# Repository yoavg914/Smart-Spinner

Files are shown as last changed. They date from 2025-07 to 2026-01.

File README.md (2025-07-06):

# Smart-Spinner
# Project A - ECE Technion - Smart Spinner

This project is a custom-built smart spinning top system designed to sense, analyze, and display rotational data in real time.
The system integrates a microcontroller, motion sensors, battery management, and wireless communication.

## Features
- Motion sensing using LSM6DSV (accelerometer + gyroscope)
- ESP32-S3 for wireless communication and data processing
- Rechargeable power system using 18650 batteries and a buck converter
- Optional remote-controlled mechanical extension via reserved hammer layout

## Goals
- Analyze spin speed and stability
- Visualize real-time motion data
- Build a modular, embedded system with future expansion in mind

## Status
🚧 Work in progress — hardware assembly and firmware development underway.

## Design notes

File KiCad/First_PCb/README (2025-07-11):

here will be all the files of the lower PCB - The main PCB.

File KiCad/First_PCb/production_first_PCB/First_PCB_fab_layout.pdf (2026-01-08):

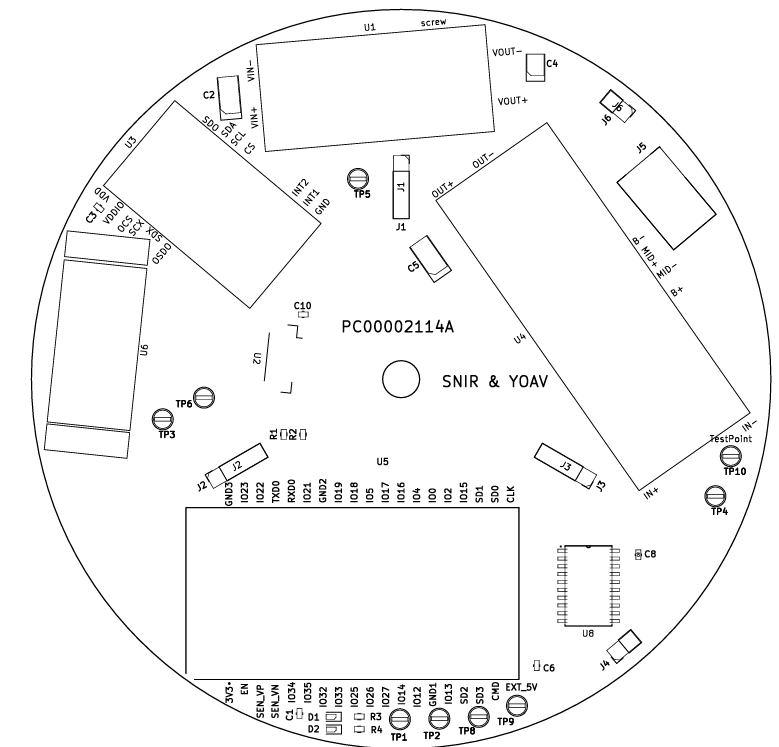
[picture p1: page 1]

First PCB – front layout

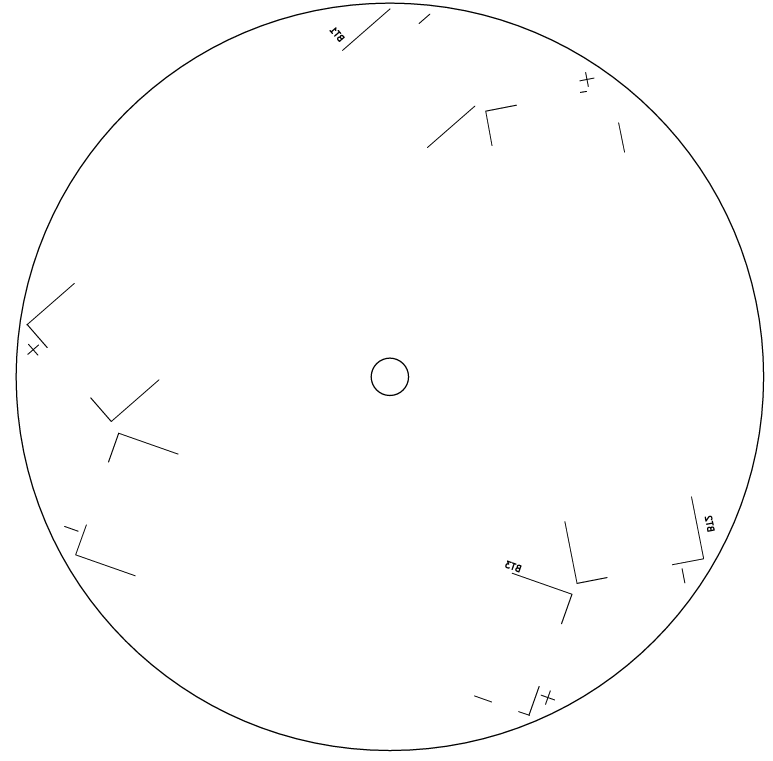
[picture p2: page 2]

First PCB – Back Layout

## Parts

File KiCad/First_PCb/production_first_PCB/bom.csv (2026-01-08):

Designator | Footprint | Quantity | Value | LCSC Part #
BT1, BT2, BT3 | battery_holder | 3 | Battery Holder
C1, C10, C3, C6, C8 | 0603 | 5 | 10u
C2, C5 | CP_EIA-6032-28_Kemet-C_HandSolder | 2 | 47u
C4 | CP_EIA-3528-12_Kemet-T_HandSolder | 1 | 47u
D1 | 0603 | 1 | red_LED
D2 | 0603 | 1 | green_LED
J1, J2, J3 | PinSocket_1x04_P2.54mm_Vertical | 3 | Conn_01x04_Socket
J4, J6 | PinHeader_1x02_P2.54mm_Vertical | 2 | Conn_01x02_Pin
J5 | NINIGI_DC-005 | 1 | DC-005
R1, R2 | 0603 | 2 | 10
R3, R4 | 0603 | 2 | 250
TP1, TP10, TP2, TP3, TP4, TP5, TP6, TP8, TP9 | TestPoint_Loop_D2.60mm_Drill1.4mm_Beaded | 9 | TestPoint
U1 | MT3608_no_conn_TH | 1 | MT3608 - No Connector
U2 | JST_GH125 | 1 | GH1.25
U3 | STEVAL-MKI239A | 1 | STEVAL-MKI239A
U4 | PWR_SPLY12V_TH | 1 | EGBO UPS
U5 | MODULE_ESP32-DEVKITC-32D-TH | 1 | ESP32-DEVKITC-32D
U6 | TF_LUNA_mechanics | 1 | TF_LUNA_mechanics
U8 | 74HCT244D-SOIC20 | 1 | 74HCT244D

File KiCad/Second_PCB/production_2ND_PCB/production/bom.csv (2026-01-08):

Designator | Footprint | Quantity | Value | LCSC Part #
C1, C2, C3, C4 | CP_EIA-3528-12_Kemet-T_HandSolder | 4 | 47u
D1, D10, D11, D12, D13, D14, D15, D16, D17, D18, D19, D2, D20, D21, D22, D23, D24, D25, D26, D27, D28, D29, D3, D30, D31, D32, D33, D34, D35, D36, D37, D38, D39, D4, D40, D5, D6, D7, D8, D9 | LED-APA102-2020_EDITED | 40 | APA102-2020
J1, J2, J3 | PinSocket_1x04_P2.54mm_Vertical | 3 | Conn_01x04_Pin
TP1, TP2, TP3, TP4, TP5 | TestPoint_Loop_D2.60mm_Drill1.4mm_Beaded | 5 | TestPoint

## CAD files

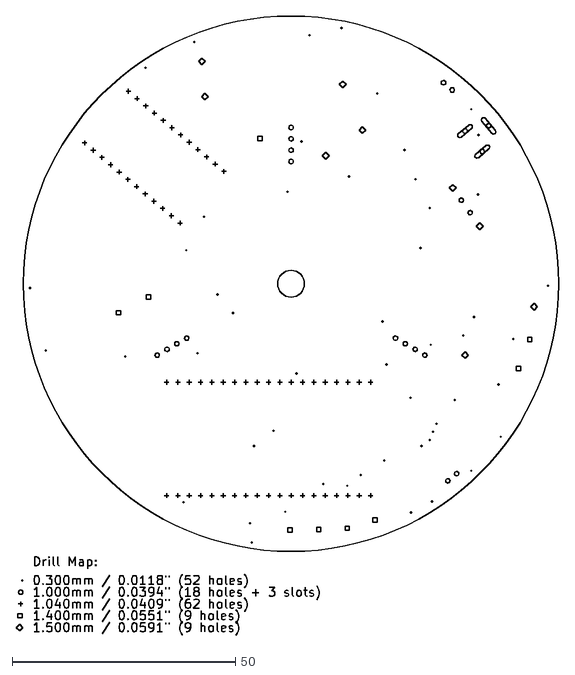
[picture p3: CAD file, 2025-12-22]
KiCad/First_PCb/first_PCB-PTH-drl_map.dxf
121.6 x 138.7

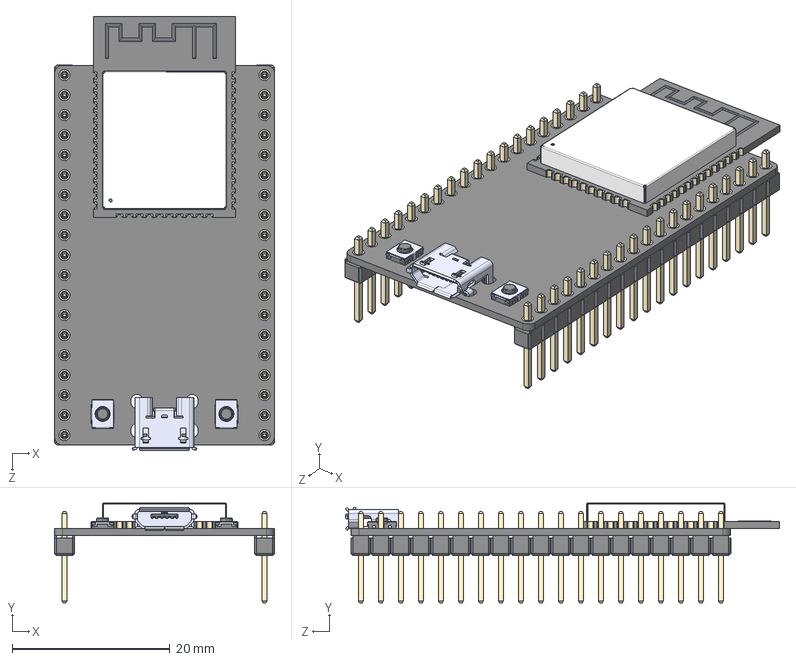
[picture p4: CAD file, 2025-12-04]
KiCad/First_PCb/scematic_symbols/ESP32-DEVKITC-32D/ESP32-DEVKITC-32D.step
27.9 x 12.7 x 55.1 mm
board
header x 2
ESP32-WROOM-32D
micro usb
button x 2

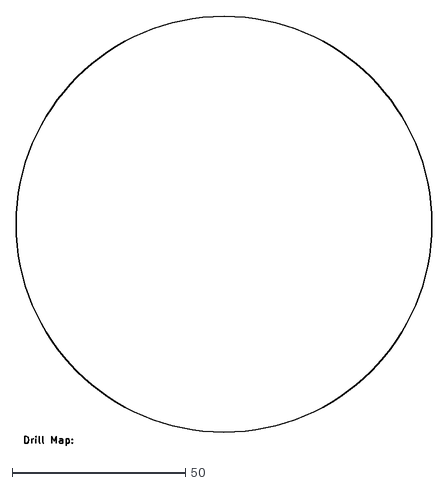
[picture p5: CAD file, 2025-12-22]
KiCad/Second_PCB/2ND_PCB-NPTH-drl_map.dxf
120.0 x 123.9

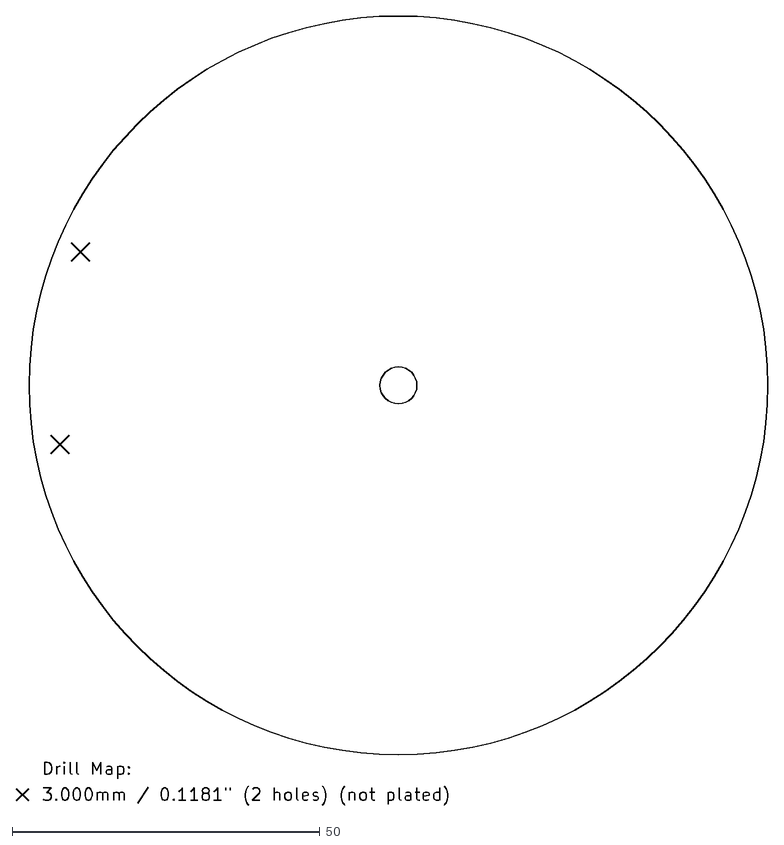
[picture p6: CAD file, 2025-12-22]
KiCad/First_PCb/first_PCB-NPTH-drl_map.dxf
122.1 x 128.2

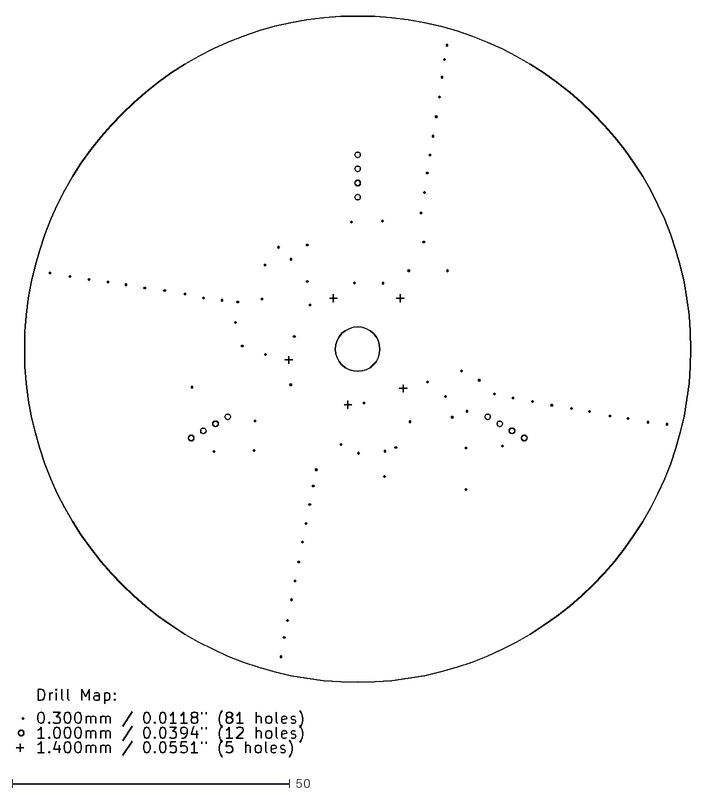
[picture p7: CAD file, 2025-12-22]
KiCad/Second_PCB/2ND_PCB-PTH-drl_map.dxf
121.5 x 133.5

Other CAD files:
3D_Files/spinning-top.f3z

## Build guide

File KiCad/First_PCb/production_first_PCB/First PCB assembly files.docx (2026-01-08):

PC00002114A – Snir & Yoav


First PCB – front layout

PC00002114A – Snir & Yoav

First PCB – Back Layout


Designator | Footprint | Quantity | Value
BT1, BT2, BT3 | battery_holder | 3 | Battery Holder
C1, C10, C3, C6, C8 | 603 | 5 | 10u
C2, C5 | CP_EIA-6032-28_Kemet-C_HandSolder | 2 | 47u
C4 | CP_EIA-3528-12_Kemet-T_HandSolder | 1 | 47u
D1 | 603 | 1 | red_LED
D2 | 603 | 1 | green_LED
J1, J2, J3 | PinSocket_1x04_P2.54mm_Vertical | 3 | Conn_01x04_Socket
J4, J6 | PinHeader_1x02_P2.54mm_Vertical | 2 | Conn_01x02_Pin
J5 | NINIGI_DC-005 | 1 | DC-005
R1, R2 | 603 | 2 | 10
R3, R4 | 603 | 2 | 250
TP1, TP10, TP2, TP3, TP4, TP5, TP6, TP8, TP9 | TestPoint_Loop_D2.60mm_Drill1.4mm_Beaded | 9 | TestPoint
U1 | MT3608_no_conn_TH | 1 | MT3608 - No Connector
U2 | JST_GH125 | 1 | GH1.25
U3 | STEVAL-MKI239A | 1 | STEVAL-MKI239A
U4 | PWR_SPLY12V_TH | 1 | EGBO UPS
U5 | MODULE_ESP32-DEVKITC-32D-TH | 1 | ESP32-DEVKITC-32D
U6 | TF_LUNA_mechanics | 1 | TF_LUNA_mechanics
U8 | 74HCT244D-SOIC20 | 1 | 74HCT244D

PC00002114A – Snir & Yoav

First PCB – BOM

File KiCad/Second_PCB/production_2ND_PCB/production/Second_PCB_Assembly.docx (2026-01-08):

PC00002115A – SNIR & YOAV - 2ND PCB BOTTOM SIDE

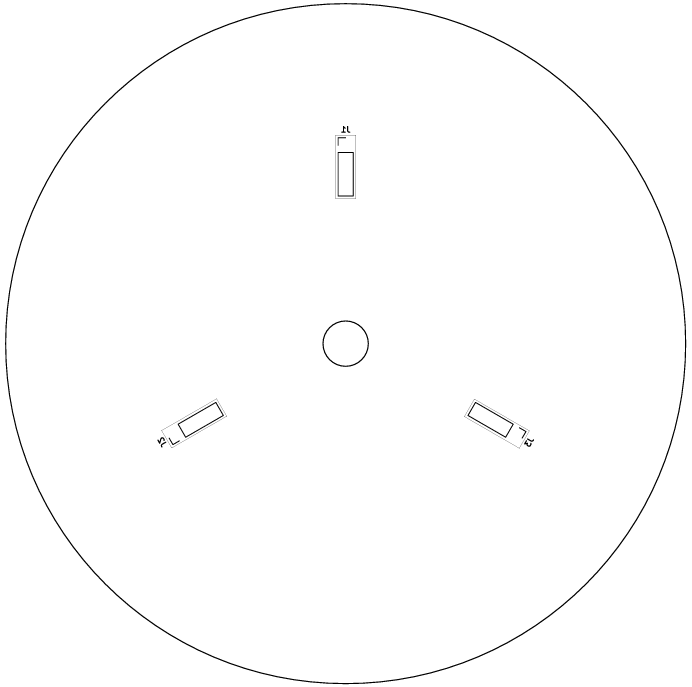
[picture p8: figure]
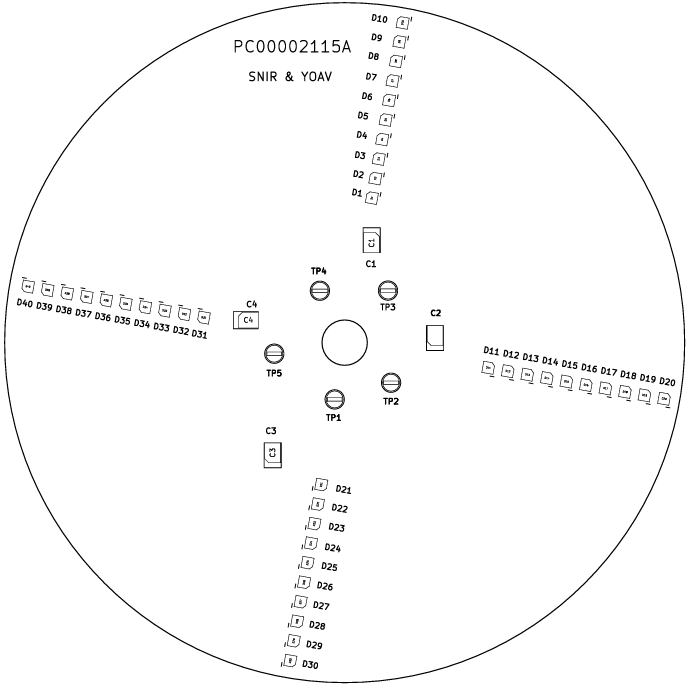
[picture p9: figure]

PC00002115A – SNIR & YOAV - 2ND PCB TOP SIDE

BOM

Designator | Footprint | Quantity | Value
C1, C2, C3, C4 | CP_EIA-3528-12_Kemet-T_HandSolder | 4 | 47u
D1, D10, D11, D12, D13, D14, D15, D16, D17, D18, D19, D2, D20, D21, D22, D23, D24, D25, D26, D27, D28, D29, D3, D30, D31, D32, D33, D34, D35, D36, D37, D38, D39, D4, D40, D5, D6, D7, D8, D9 | LED-APA102-2020_EDITED | 40 | APA102-2020
J1, J2, J3 | PinSocket_1x04_P2.54mm_Vertical | 3 | Conn_01x04_Pin
TP1, TP2, TP3, TP4, TP5 | TestPoint_Loop_D2.60mm_Drill1.4mm_Beaded | 5 | TestPoint

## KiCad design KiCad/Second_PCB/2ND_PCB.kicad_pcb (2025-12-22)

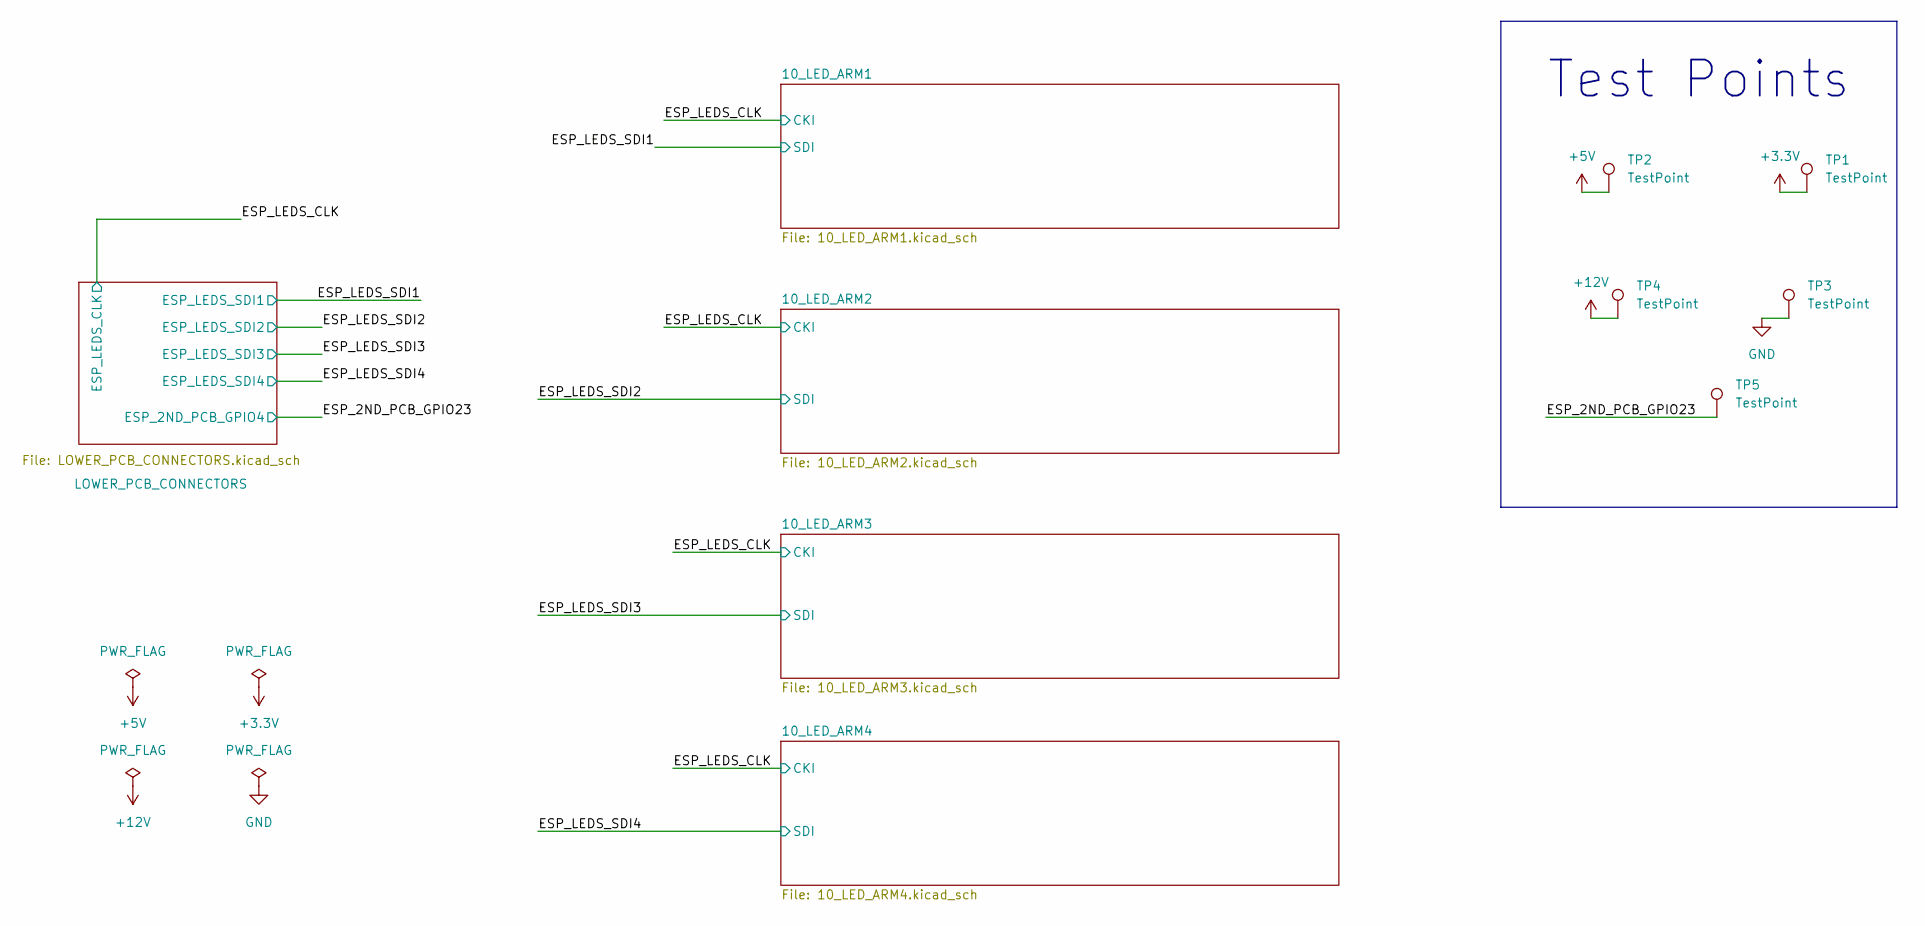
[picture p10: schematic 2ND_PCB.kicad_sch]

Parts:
TP1, TP2, TP3, TP4, TP5: TestPoint; TestPoint_Loop_D2.60mm_Drill1.4mm_Beaded

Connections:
+3.3V: TP1.1; also elsewhere on the board
+5V: TP2.1; also elsewhere on the board
+12V: TP4.1; also elsewhere on the board
/ESP_2ND_PCB_GPIO23: TP5.1; also elsewhere on the board
GND: TP3.1; also elsewhere on the board

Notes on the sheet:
Test Points

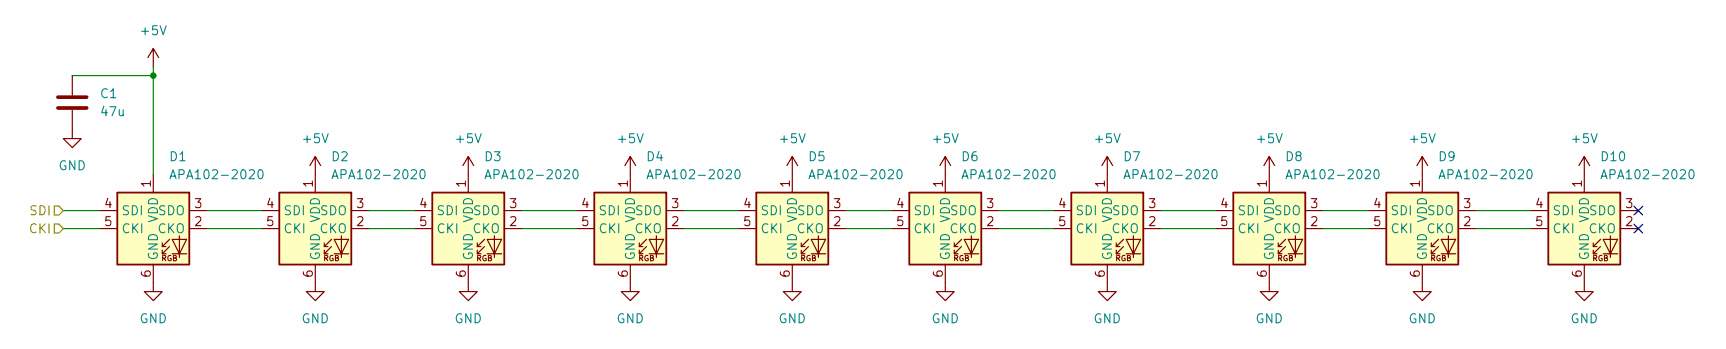
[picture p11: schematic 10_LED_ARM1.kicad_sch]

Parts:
C1: 47u; CP_EIA-3528-12_Kemet-T_HandSolder
D1, D2, D3, D4, D5, D6, D7, D8, D9, D10: APA102-2020; LED-APA102-2020_EDITED

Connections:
+5V: C1.1, D1.1 (VDD), D2.1 (VDD), D3.1 (VDD), D4.1 (VDD), D5.1 (VDD), D6.1 (VDD), D7.1 (VDD), D8.1 (VDD), D9.1 (VDD), D10.1 (VDD); also elsewhere on the board
/ESP_LEDS_CLK: D1.5 (CKI); also elsewhere on the board
/ESP_LEDS_SDI1: D1.4 (SDI); also elsewhere on the board
GND: C1.2, D1.6 (GND), D2.6 (GND), D3.6 (GND), D4.6 (GND), D5.6 (GND), D6.6 (GND), D7.6 (GND), D8.6 (GND), D9.6 (GND), D10.6 (GND); also elsewhere on the board
unnamed: D1.2 (CKO), D2.5 (CKI)
unnamed: D1.3 (SDO), D2.4 (SDI)
unnamed: D2.2 (CKO), D3.5 (CKI)
unnamed: D2.3 (SDO), D3.4 (SDI)
unnamed: D3.2 (CKO), D4.5 (CKI)
unnamed: D3.3 (SDO), D4.4 (SDI)
unnamed: D4.2 (CKO), D5.5 (CKI)
unnamed: D4.3 (SDO), D5.4 (SDI)
unnamed: D5.2 (CKO), D6.5 (CKI)
unnamed: D5.3 (SDO), D6.4 (SDI)
unnamed: D6.2 (CKO), D7.5 (CKI)
unnamed: D6.3 (SDO), D7.4 (SDI)
unnamed: D7.2 (CKO), D8.5 (CKI)
unnamed: D7.3 (SDO), D8.4 (SDI)
unnamed: D8.2 (CKO), D9.5 (CKI)
unnamed: D8.3 (SDO), D9.4 (SDI)
unnamed: D9.2 (CKO), D10.5 (CKI)
unnamed: D9.3 (SDO), D10.4 (SDI)

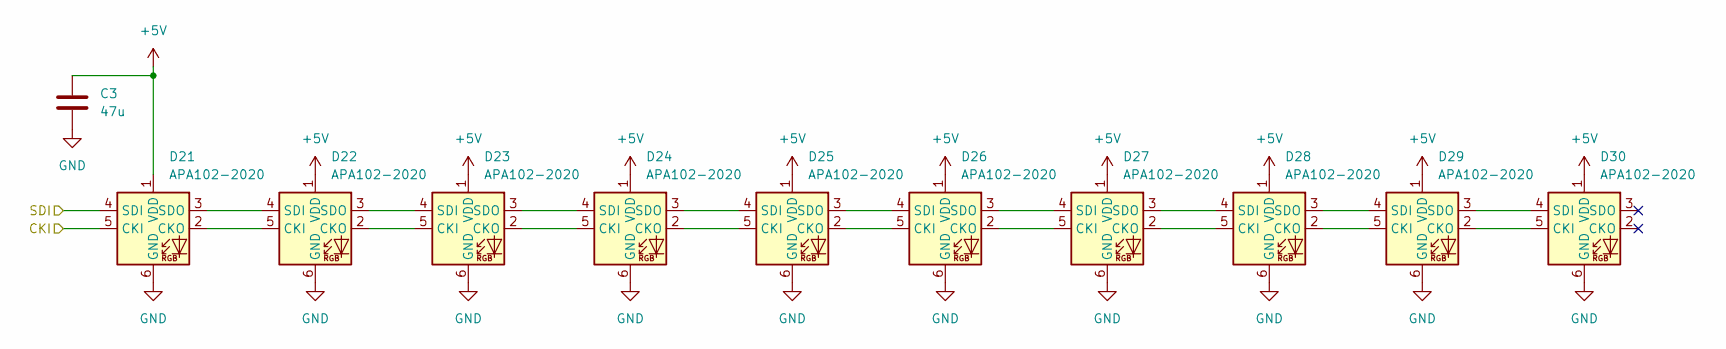
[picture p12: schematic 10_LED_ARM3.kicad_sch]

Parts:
C3: 47u; CP_EIA-3528-12_Kemet-T_HandSolder
D21, D22, D23, D24, D25, D26, D27, D28, D29, D30: APA102-2020; LED-APA102-2020_EDITED

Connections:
+5V: C3.1, D21.1 (VDD), D22.1 (VDD), D23.1 (VDD), D24.1 (VDD), D25.1 (VDD), D26.1 (VDD), D27.1 (VDD), D28.1 (VDD), D29.1 (VDD), D30.1 (VDD); also elsewhere on the board
/ESP_LEDS_CLK: D21.5 (CKI); also elsewhere on the board
/ESP_LEDS_SDI3: D21.4 (SDI); also elsewhere on the board
GND: C3.2, D21.6 (GND), D22.6 (GND), D23.6 (GND), D24.6 (GND), D25.6 (GND), D26.6 (GND), D27.6 (GND), D28.6 (GND), D29.6 (GND), D30.6 (GND); also elsewhere on the board
unnamed: D21.2 (CKO), D22.5 (CKI)
unnamed: D21.3 (SDO), D22.4 (SDI)
unnamed: D22.2 (CKO), D23.5 (CKI)
unnamed: D22.3 (SDO), D23.4 (SDI)
unnamed: D23.2 (CKO), D24.5 (CKI)
unnamed: D23.3 (SDO), D24.4 (SDI)
unnamed: D24.2 (CKO), D25.5 (CKI)
unnamed: D24.3 (SDO), D25.4 (SDI)
unnamed: D25.2 (CKO), D26.5 (CKI)
unnamed: D25.3 (SDO), D26.4 (SDI)
unnamed: D26.2 (CKO), D27.5 (CKI)
unnamed: D26.3 (SDO), D27.4 (SDI)
unnamed: D27.2 (CKO), D28.5 (CKI)
unnamed: D27.3 (SDO), D28.4 (SDI)
unnamed: D28.2 (CKO), D29.5 (CKI)
unnamed: D28.3 (SDO), D29.4 (SDI)
unnamed: D29.2 (CKO), D30.5 (CKI)
unnamed: D29.3 (SDO), D30.4 (SDI)

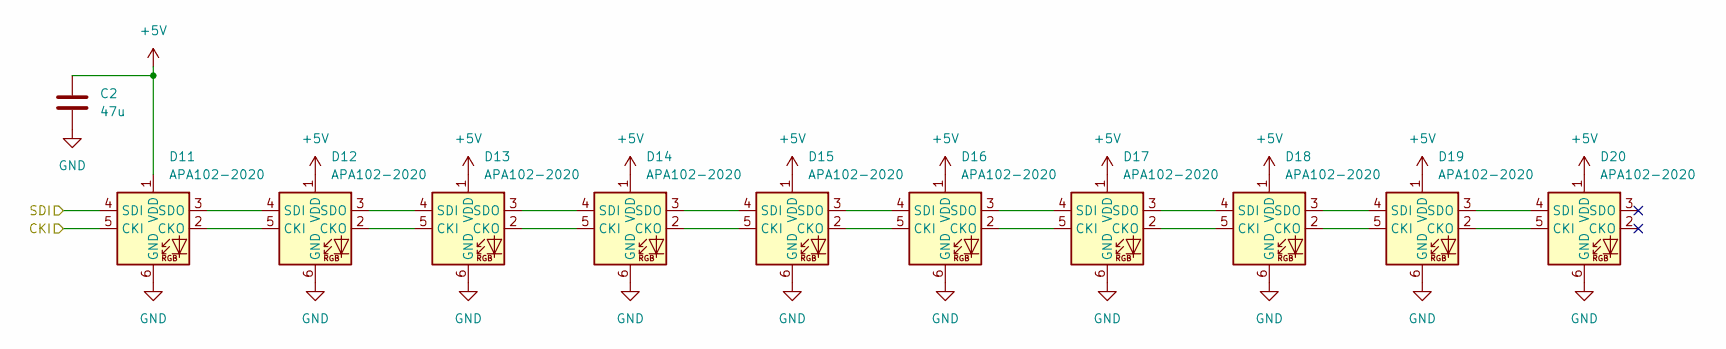
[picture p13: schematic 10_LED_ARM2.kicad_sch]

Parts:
C2: 47u; CP_EIA-3528-12_Kemet-T_HandSolder
D11, D12, D13, D14, D15, D16, D17, D18, D19, D20: APA102-2020; LED-APA102-2020_EDITED

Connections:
+5V: C2.1, D11.1 (VDD), D12.1 (VDD), D13.1 (VDD), D14.1 (VDD), D15.1 (VDD), D16.1 (VDD), D17.1 (VDD), D18.1 (VDD), D19.1 (VDD), D20.1 (VDD); also elsewhere on the board
/ESP_LEDS_CLK: D11.5 (CKI); also elsewhere on the board
/ESP_LEDS_SDI2: D11.4 (SDI); also elsewhere on the board
GND: C2.2, D11.6 (GND), D12.6 (GND), D13.6 (GND), D14.6 (GND), D15.6 (GND), D16.6 (GND), D17.6 (GND), D18.6 (GND), D19.6 (GND), D20.6 (GND); also elsewhere on the board
unnamed: D11.2 (CKO), D12.5 (CKI)
unnamed: D11.3 (SDO), D12.4 (SDI)
unnamed: D12.2 (CKO), D13.5 (CKI)
unnamed: D12.3 (SDO), D13.4 (SDI)
unnamed: D13.2 (CKO), D14.5 (CKI)
unnamed: D13.3 (SDO), D14.4 (SDI)
unnamed: D14.2 (CKO), D15.5 (CKI)
unnamed: D14.3 (SDO), D15.4 (SDI)
unnamed: D15.2 (CKO), D16.5 (CKI)
unnamed: D15.3 (SDO), D16.4 (SDI)
unnamed: D16.2 (CKO), D17.5 (CKI)
unnamed: D16.3 (SDO), D17.4 (SDI)
unnamed: D17.2 (CKO), D18.5 (CKI)
unnamed: D17.3 (SDO), D18.4 (SDI)
unnamed: D18.2 (CKO), D19.5 (CKI)
unnamed: D18.3 (SDO), D19.4 (SDI)
unnamed: D19.2 (CKO), D20.5 (CKI)
unnamed: D19.3 (SDO), D20.4 (SDI)

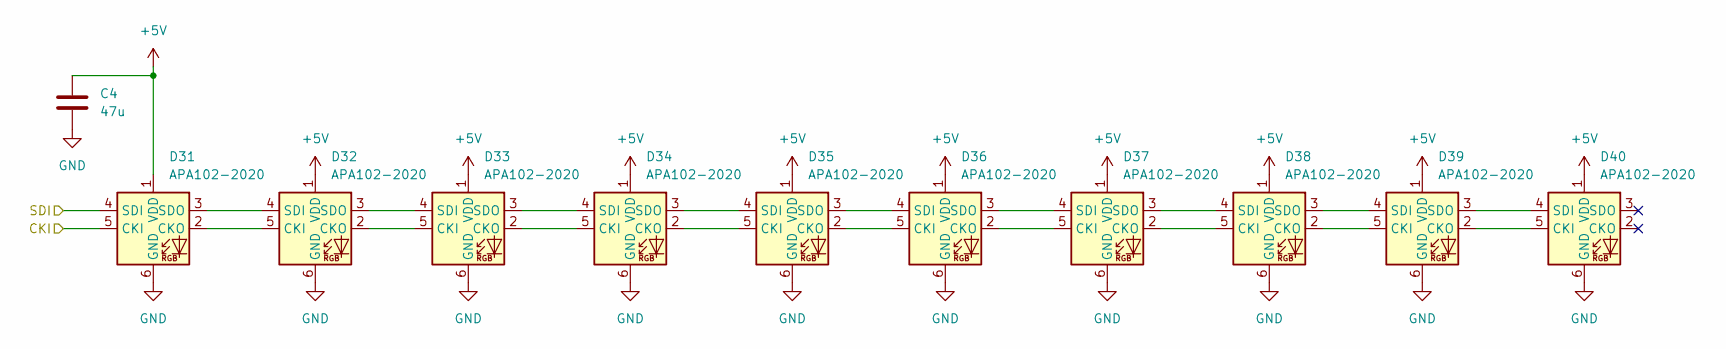
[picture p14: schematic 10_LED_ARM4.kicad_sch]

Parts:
C4: 47u; CP_EIA-3528-12_Kemet-T_HandSolder
D31, D32, D33, D34, D35, D36, D37, D38, D39, D40: APA102-2020; LED-APA102-2020_EDITED

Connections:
+5V: C4.1, D31.1 (VDD), D32.1 (VDD), D33.1 (VDD), D34.1 (VDD), D35.1 (VDD), D36.1 (VDD), D37.1 (VDD), D38.1 (VDD), D39.1 (VDD), D40.1 (VDD); also elsewhere on the board
/ESP_LEDS_CLK: D31.5 (CKI); also elsewhere on the board
/ESP_LEDS_SDI4: D31.4 (SDI); also elsewhere on the board
GND: C4.2, D31.6 (GND), D32.6 (GND), D33.6 (GND), D34.6 (GND), D35.6 (GND), D36.6 (GND), D37.6 (GND), D38.6 (GND), D39.6 (GND), D40.6 (GND); also elsewhere on the board
unnamed: D31.2 (CKO), D32.5 (CKI)
unnamed: D31.3 (SDO), D32.4 (SDI)
unnamed: D32.2 (CKO), D33.5 (CKI)
unnamed: D32.3 (SDO), D33.4 (SDI)
unnamed: D33.2 (CKO), D34.5 (CKI)
unnamed: D33.3 (SDO), D34.4 (SDI)
unnamed: D34.2 (CKO), D35.5 (CKI)
unnamed: D34.3 (SDO), D35.4 (SDI)
unnamed: D35.2 (CKO), D36.5 (CKI)
unnamed: D35.3 (SDO), D36.4 (SDI)
unnamed: D36.2 (CKO), D37.5 (CKI)
unnamed: D36.3 (SDO), D37.4 (SDI)
unnamed: D37.2 (CKO), D38.5 (CKI)
unnamed: D37.3 (SDO), D38.4 (SDI)
unnamed: D38.2 (CKO), D39.5 (CKI)
unnamed: D38.3 (SDO), D39.4 (SDI)
unnamed: D39.2 (CKO), D40.5 (CKI)
unnamed: D39.3 (SDO), D40.4 (SDI)

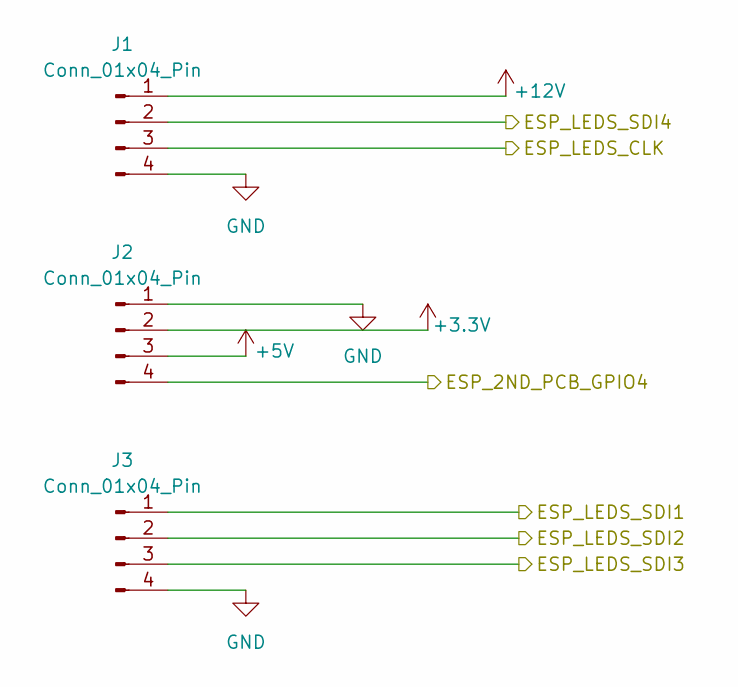
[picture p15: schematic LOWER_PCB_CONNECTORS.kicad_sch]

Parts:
J1, J2, J3: Conn_01x04_Pin; PinSocket_1x04_P2.54mm_Vertical

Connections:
+3.3V: J2.2; also elsewhere on the board
+5V: J2.3; also elsewhere on the board
+12V: J1.1; also elsewhere on the board
/ESP_2ND_PCB_GPIO23: J2.4; also elsewhere on the board
/ESP_LEDS_CLK: J1.3; also elsewhere on the board
/ESP_LEDS_SDI1: J3.1; also elsewhere on the board
/ESP_LEDS_SDI2: J3.2; also elsewhere on the board
/ESP_LEDS_SDI3: J3.3; also elsewhere on the board
/ESP_LEDS_SDI4: J1.2; also elsewhere on the board
GND: J1.4, J2.1, J3.4; also elsewhere on the board

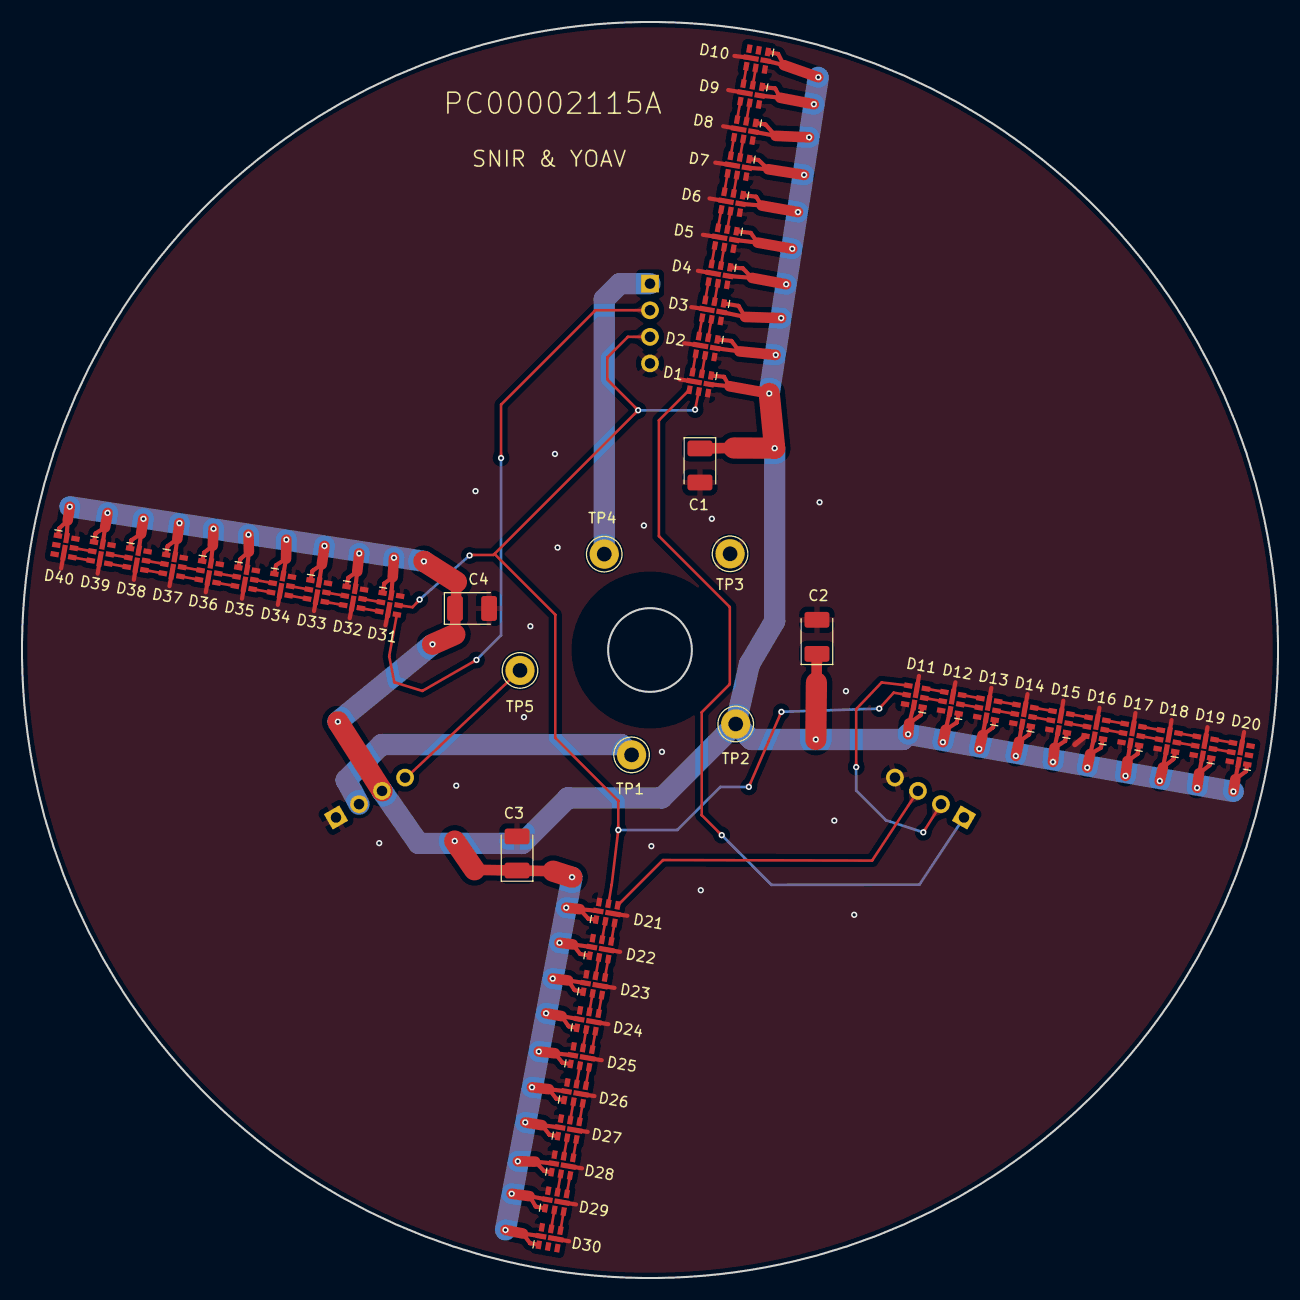
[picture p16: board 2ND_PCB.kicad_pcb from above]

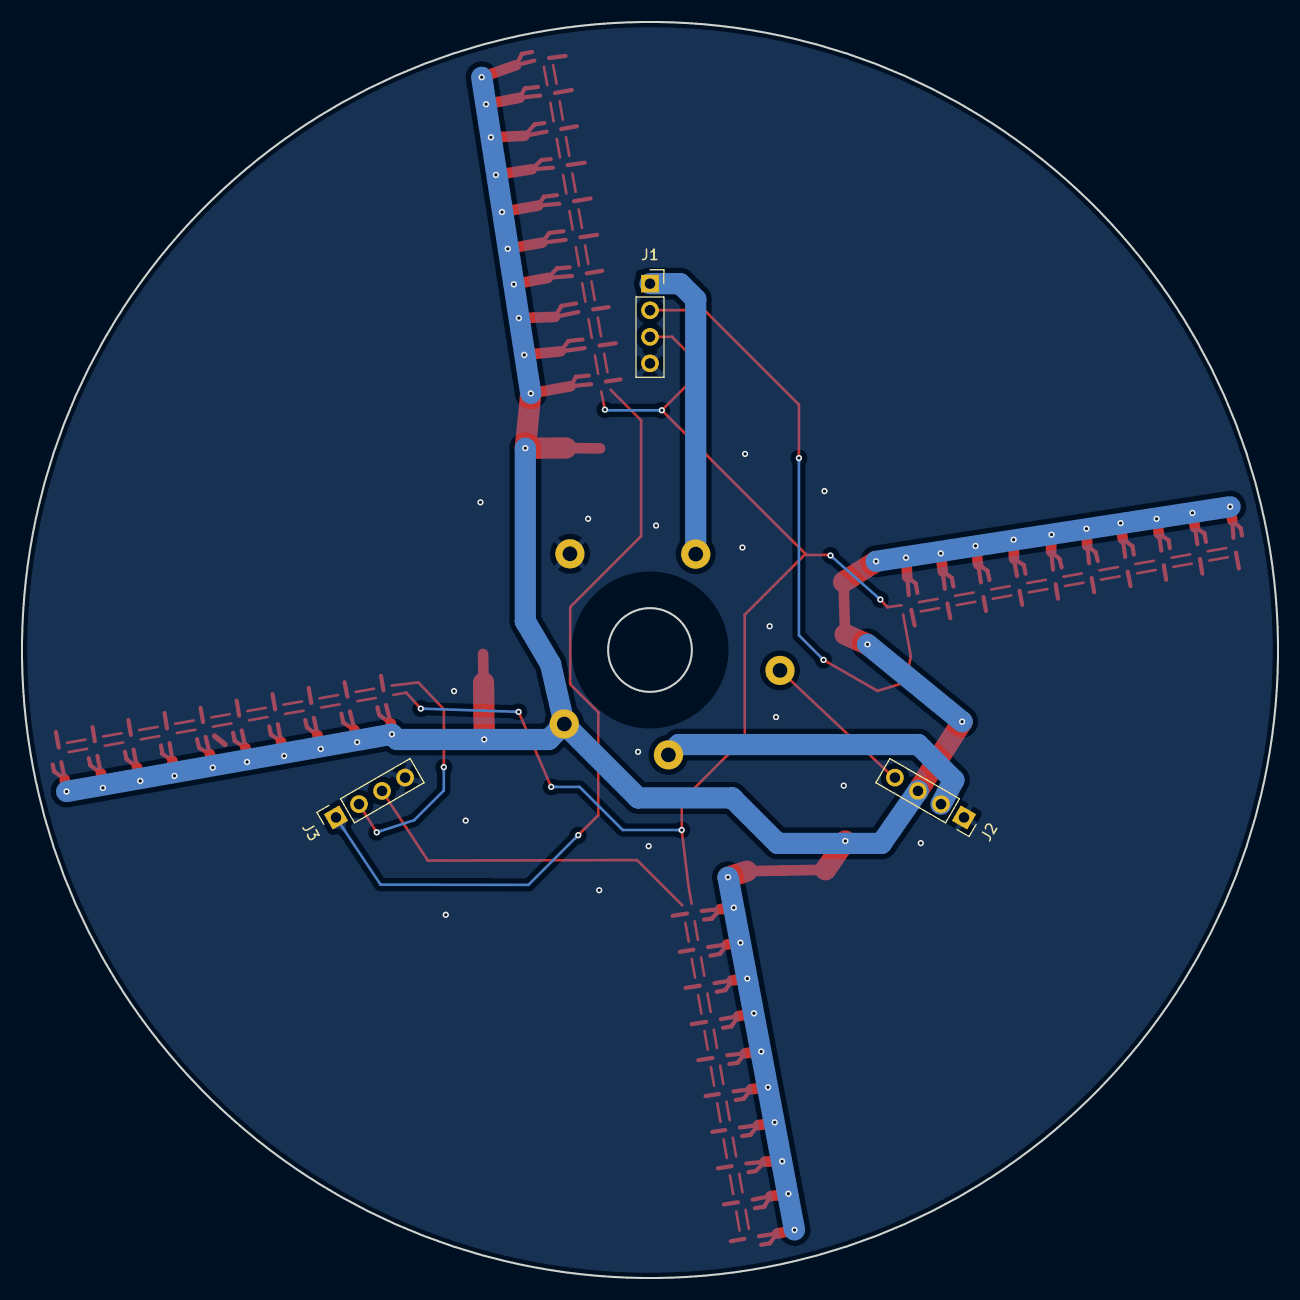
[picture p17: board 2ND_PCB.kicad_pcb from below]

Board: 2 copper layers, 120.0 x 120.0 mm, 52 parts (3 on the bottom side), 82 nets.

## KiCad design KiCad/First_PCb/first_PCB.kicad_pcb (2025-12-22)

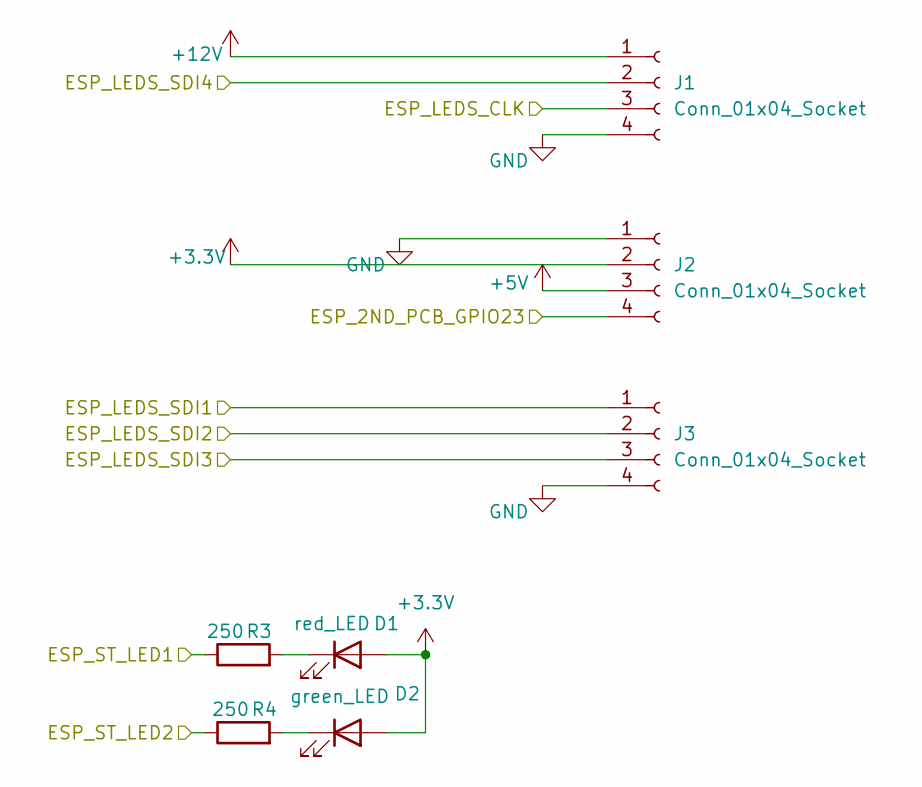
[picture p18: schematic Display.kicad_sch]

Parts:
D1: red_LED; LED_0603_1608Metric_Pad1.05x0.95mm_HandSolder
D2: green_LED; LED_0603_1608Metric_Pad1.05x0.95mm_HandSolder
J1, J2, J3: Conn_01x04_Socket; PinSocket_1x04_P2.54mm_Vertical
R3, R4: 250; R_0603_1608Metric_Pad0.98x0.95mm_HandSolder

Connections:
+3.3V: D1.2 (A), D2.2 (A), J2.2; also elsewhere on the board
+5V: J2.3; also elsewhere on the board
+12V: J1.1; also elsewhere on the board
/Processing/ESP_2ND_PCB_GPIO23: J2.4; also elsewhere on the board
/Processing/ESP_LEDS_CLK: J1.3; also elsewhere on the board
/Processing/ESP_LEDS_SDI1: J3.1; also elsewhere on the board
/Processing/ESP_LEDS_SDI2: J3.2; also elsewhere on the board
/Processing/ESP_LEDS_SDI3: J3.3; also elsewhere on the board
/Processing/ESP_LEDS_SDI4: J1.2; also elsewhere on the board
/Processing/ESP_ST_LED1: R3.1; also elsewhere on the board
/Processing/ESP_ST_LED2: R4.1; also elsewhere on the board
GND: J1.4, J2.1, J3.4; also elsewhere on the board
unnamed: D1.1 (K), R3.2
unnamed: D2.1 (K), R4.2

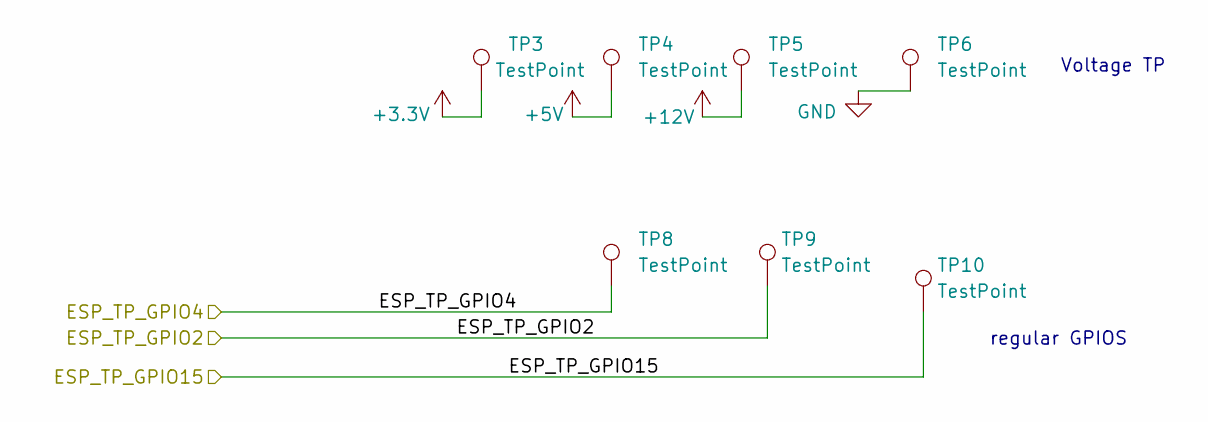
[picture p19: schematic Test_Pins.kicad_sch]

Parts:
TP3, TP4, TP5, TP6, TP8, TP9, TP10: TestPoint; TestPoint_Loop_D2.60mm_Drill1.4mm_Beaded

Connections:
+3.3V: TP3.1; also elsewhere on the board
+5V: TP4.1; also elsewhere on the board
+12V: TP5.1; also elsewhere on the board
/Processing/ESP_TP_GPIO2: TP9.1; also elsewhere on the board
/Processing/ESP_TP_GPIO15: TP10.1; also elsewhere on the board
/Test Pins/ESP_TP_GPIO4: TP8.1; also elsewhere on the board
GND: TP6.1; also elsewhere on the board

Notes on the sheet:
regular GPIOS
Voltage TP

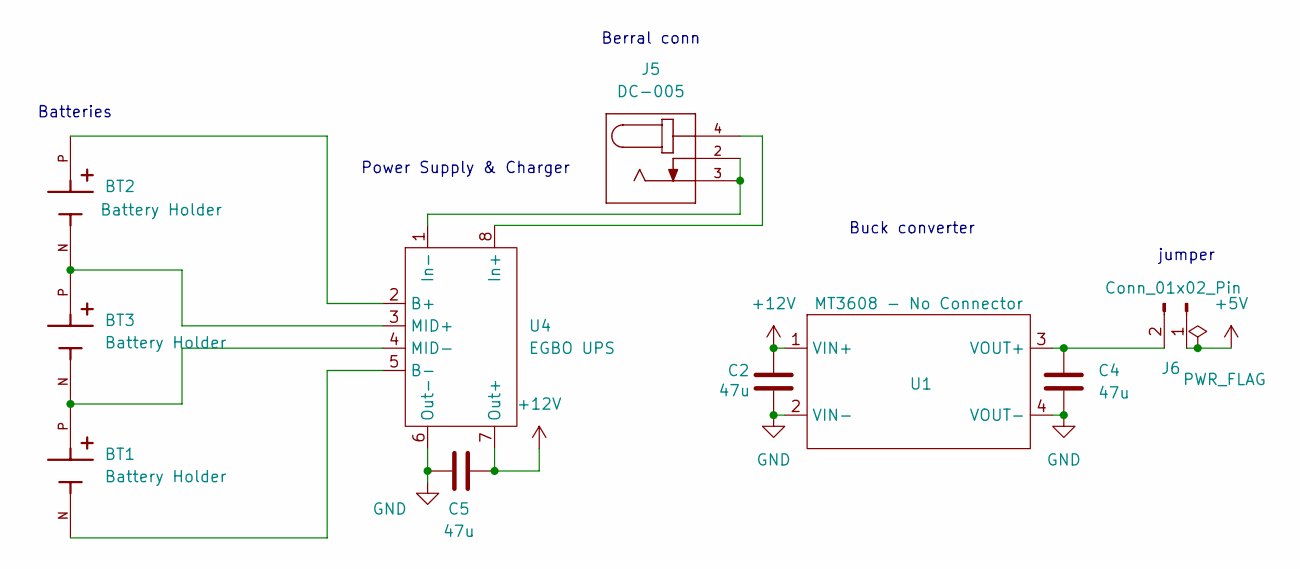
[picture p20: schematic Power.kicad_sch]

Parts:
BT1, BT2, BT3: Battery Holder; battery_holder
C2, C5: 47u; CP_EIA-6032-28_Kemet-C_HandSolder
C4: 47u; CP_EIA-3528-12_Kemet-T_HandSolder
J5: DC-005; NINIGI_DC-005
J6: Conn_01x02_Pin; PinHeader_1x02_P2.54mm_Vertical
U1: MT3608 - No Connector; MT3608_no_conn_TH
U4: EGBO UPS; PWR_SPLY12V_TH

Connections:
+5V: J6.1; also elsewhere on the board
+12V: C2.1, C5.2, U1.1 (VIN+), U4.7 (Out+); also elsewhere on the board
GND: C2.2, C4.2, C5.1, U1.2 (VIN-), U1.4 (VOUT-), U4.6 (Out-); also elsewhere on the board
unnamed: C4.1, J6.2, U1.3 (VOUT+)
unnamed: BT2.P, U4.2 (B+)
unnamed: BT1.N, U4.5 (B-)
unnamed: J5.4, U4.8 (In+)
unnamed: J5.2, J5.3, U4.1 (In-)
unnamed: BT2.N, BT3.P, U4.3 (MID+)
unnamed: BT1.P, BT3.N, U4.4 (MID-)

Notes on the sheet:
Berral conn
Batteries
jumper
Power Supply & Charger
Buck converter

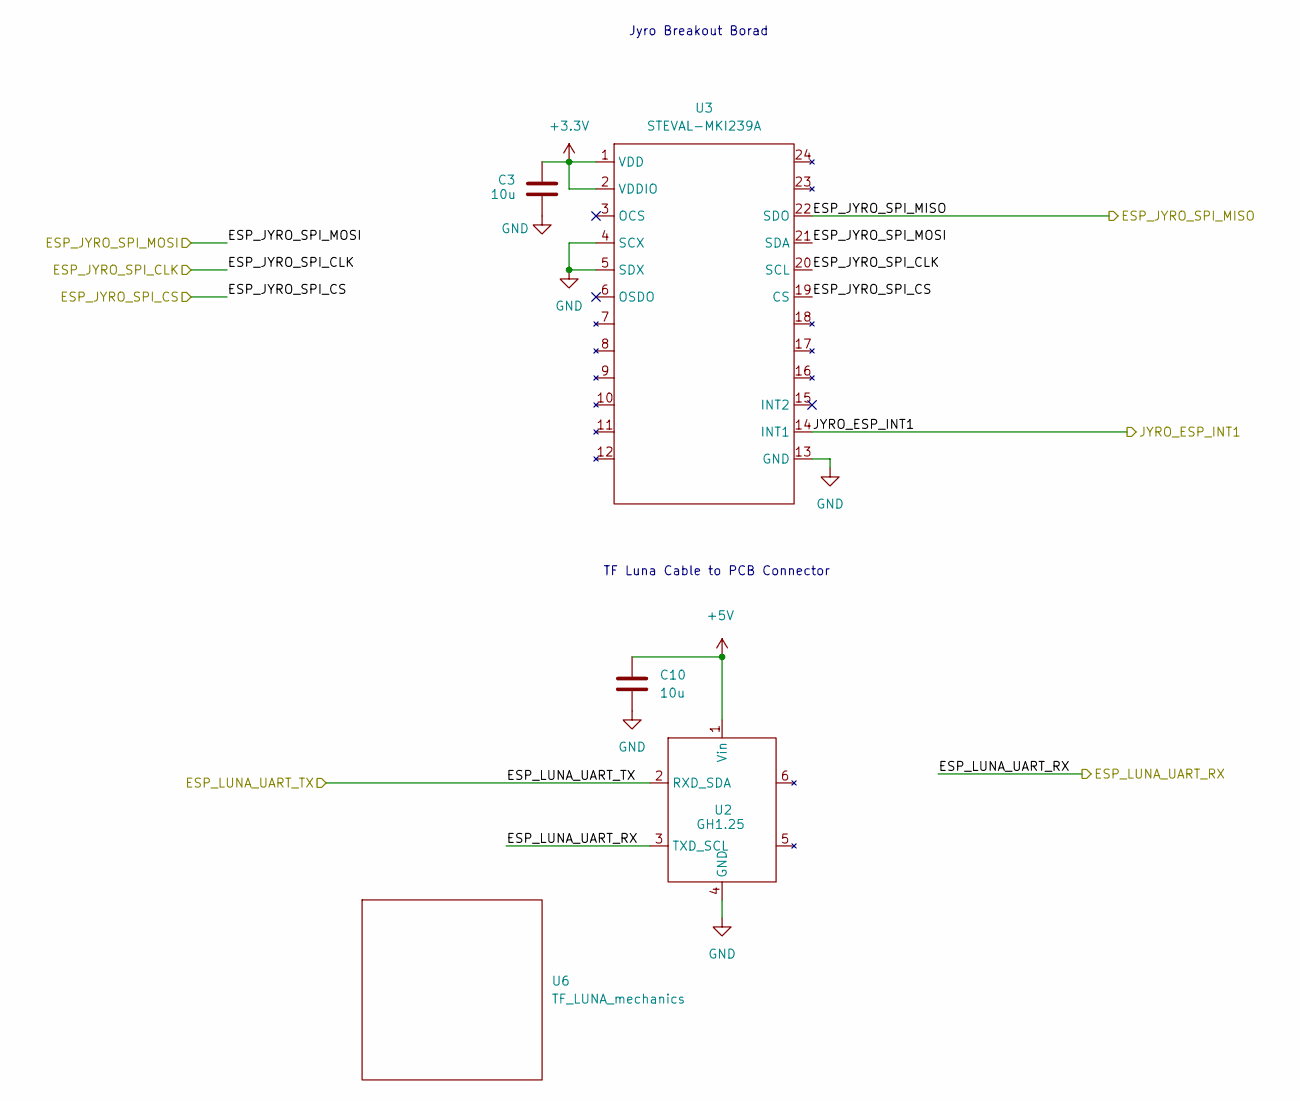
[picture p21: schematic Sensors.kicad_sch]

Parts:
C3, C10: 10u; C_0603_1608Metric_Pad1.08x0.95mm_HandSolder
U2: GH1.25; JST_GH125
U3: STEVAL-MKI239A
U6: TF_LUNA_mechanics

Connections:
+3.3V: C3.1, U3.1 (VDD), U3.2 (VDDIO); also elsewhere on the board
+5V: C10.1, U2.1 (Vin); also elsewhere on the board
/Processing/ESP_JYRO_SPI_CLK: U3.20 (SCL); also elsewhere on the board
/Processing/ESP_JYRO_SPI_CS: U3.19 (CS); also elsewhere on the board
/Processing/ESP_JYRO_SPI_MISO: U3.22 (SDO); also elsewhere on the board
/Processing/ESP_JYRO_SPI_MOSI: U3.21 (SDA); also elsewhere on the board
/Processing/ESP_LUNA_UART_RX: U2.3 (TXD_SCL); also elsewhere on the board
/Processing/ESP_LUNA_UART_TX: U2.2 (RXD_SDA); also elsewhere on the board
/Processing/JYRO_ESP_INT1: U3.14 (INT1); also elsewhere on the board
GND: C3.2, C10.2, U2.4 (GND), U3.4 (SCX), U3.5 (SDX), U3.13 (GND); also elsewhere on the board

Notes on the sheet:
TF Luna Cable to PCB Connector
Jyro Breakout Borad


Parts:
C1, C6, C8: 10u; C_0603_1608Metric_Pad1.08x0.95mm_HandSolder
J4: Conn_01x02_Pin; PinHeader_1x02_P2.54mm_Vertical
R1, R2: 10; R_0603_1608Metric_Pad0.98x0.95mm_HandSolder
TP1, TP2: TestPoint; TestPoint_Loop_D2.60mm_Drill1.4mm_Beaded
U5: ESP32-DEVKITC-32D; MODULE_ESP32-DEVKITC-32D-TH; PARTREV V4
U8: 74HCT244D; 74HCT244D-SOIC20; DigiKey_Part_Number 2156-SN74HCT244DW-ND

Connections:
+3.3V: C1.1, U5.J2-1 (3V3); also elsewhere on the board
+5V: C8.1, J4.2, U8.20 (VCC); also elsewhere on the board
/Processing/ESP_2ND_PCB_GPIO23: U5.J3-2 (IO23); also elsewhere on the board
/Processing/ESP_JYRO_SPI_CLK: U5.J3-10 (IO5); also elsewhere on the board
/Processing/ESP_JYRO_SPI_CS: U5.J3-11 (IO17); also elsewhere on the board
/Processing/ESP_JYRO_SPI_MISO: U5.J3-8 (IO19); also elsewhere on the board
/Processing/ESP_JYRO_SPI_MOSI: U5.J3-9 (IO18); also elsewhere on the board
/Processing/ESP_LEDS_CLK: U8.9 (2Y1); also elsewhere on the board
/Processing/ESP_LEDS_CLK_3.3v: U5.J2-15 (IO13), U8.11 (2A1)
/Processing/ESP_LEDS_SDI1: U8.18 (1Y1); also elsewhere on the board
/Processing/ESP_LEDS_SDI1_3.3v: U5.J2-9 (IO25), U8.2 (1A1)
/Processing/ESP_LEDS_SDI2: U8.16 (1Y2); also elsewhere on the board
/Processing/ESP_LEDS_SDI2_3.3v: U5.J2-10 (IO26), U8.4 (1A2)
/Processing/ESP_LEDS_SDI3: U8.14 (1Y3); also elsewhere on the board
/Processing/ESP_LEDS_SDI3_3.3v: U5.J2-11 (IO27), U8.6 (1A3)
/Processing/ESP_LEDS_SDI4: U8.12 (1Y4); also elsewhere on the board
/Processing/ESP_LEDS_SDI4_3.3v: U5.J2-12 (IO14), U8.8 (1A4)
/Processing/ESP_LUNA_UART_RX: R1.2; also elsewhere on the board
/Processing/ESP_LUNA_UART_TX: R2.2; also elsewhere on the board
/Processing/ESP_ST_LED1: U5.J2-7 (IO32); also elsewhere on the board
/Processing/ESP_ST_LED2: U5.J2-8 (IO33); also elsewhere on the board
/Processing/ESP_TP_GPIO2: U5.J3-15 (IO2); also elsewhere on the board
/Processing/ESP_TP_GPIO15: U5.J3-16 (IO15); also elsewhere on the board
/Processing/ESP_debug_RX: TP2.1, U5.J3-5 (RXD0)
/Processing/ESP_debug_TX: TP1.1, U5.J3-4 (TXD0)
/Processing/JYRO_ESP_INT1: U5.J3-12 (IO16); also elsewhere on the board
/Test Pins/ESP_TP_GPIO4: U5.J3-13 (IO4); also elsewhere on the board
GND: C1.2, C6.2, C8.2, U5.J2-14 (GND1), U5.J3-1 (GND3), U5.J3-7 (GND2), U8.1 (1~OE), U8.10 (GND), U8.13 (2A2), U8.15 (2A3), U8.17 (2A4), U8.19 (2~OE); also elsewhere on the board
unnamed: C6.1, J4.1, U5.J2-19 (EXT_5V)
unnamed: R2.1, U5.J3-6 (IO21)
unnamed: R1.1, U5.J3-3 (IO22)

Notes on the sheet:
jumper
ESP32 devkit C

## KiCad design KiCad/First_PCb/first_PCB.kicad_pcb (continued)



Board: 2 copper layers, 120.0 x 120.0 mm, 39 parts (3 on the bottom side), 41 nets.

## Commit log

2025-07-06 Create REAME.txt
    in KICad
2025-07-06 added KICad files
    First Versions
    [4LED_Arms.kicad_sch, 8LEDs.kicad_sch, Layer_1_Bottom.kicad_sch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]
2025-07-11 Create First PCB
2025-07-11 Update and rename KiCad_files/Layer_1_Bottom.kicad_sch to KiCad_files/FIrst_PCB/Layer_1_Bottom.kicad_sch
    [Layer_1_Bottom.kicad_sch]
2025-07-11 Update and rename KiCad_files/8LEDs.kicad_sch to KiCad_files/First_PCB/LEDs.kicad_sch
    [LEDs.kicad_sch]
2025-07-11 Update and rename Layer_1_Bottom.kicad_sch to Layer_1_Bottom.kicad_sch
    [Layer_1_Bottom.kicad_sch]
2025-07-11 First arrengement - after conversiation with Boaz
    [Buck_Converter.kicad_sch, Display.kicad_sch, Power.kicad_sch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]
2025-12-22 added all the kicad files & gerbers of the first pcb
    [Display.kicad_sch, Power.kicad_sch, Processing.kicad_sch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]
2025-12-22 adding footprints and schematic symbols libraries
2025-12-22 added all the kicad files and gerbers of the second pcb
    after sending to manufacture.
    [10_LED_ARM1.kicad_sch, 10_LED_ARM2.kicad_sch, 10_LED_ARM3.kicad_sch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]
2026-01-08 added production files
    BOM & Netlist
    [bom.csv, designators.csv, positions.csv]
2026-01-08 added production files - Second PCB
    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
    [bom.csv, designators.csv, positions.csv]
2026-01-08 assembly and fab files
    - for soldering irena - first pcb
2026-01-08 assembly layout and BOM files
    for assembly and soldering
